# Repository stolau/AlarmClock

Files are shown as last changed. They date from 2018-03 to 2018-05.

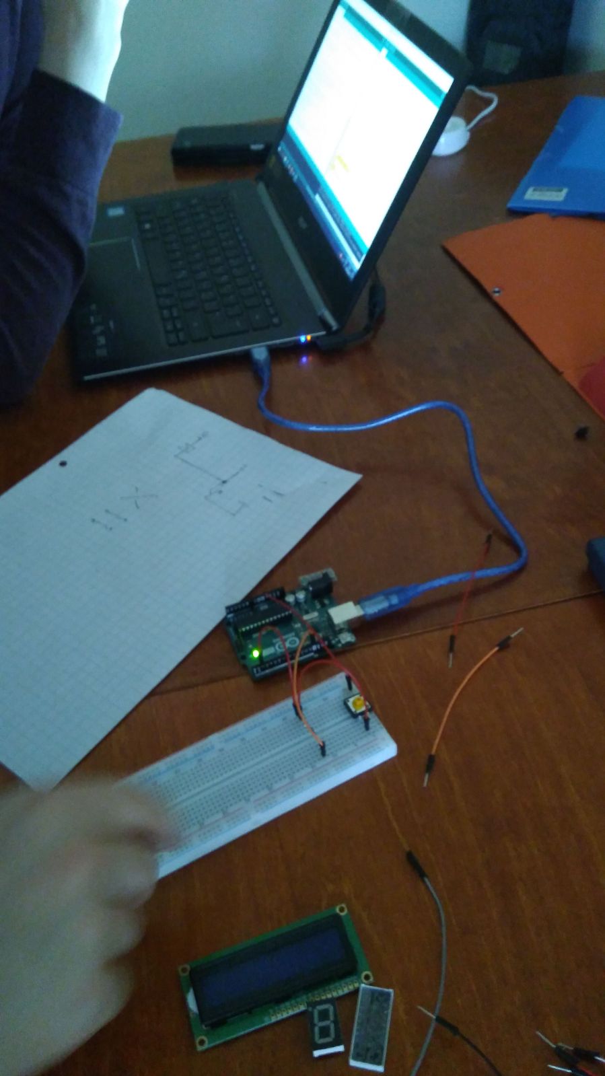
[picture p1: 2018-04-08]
Week 2 Report/Pictures/34270d8d-cade-4d01-affd-24c37ad5ccd0.jpg

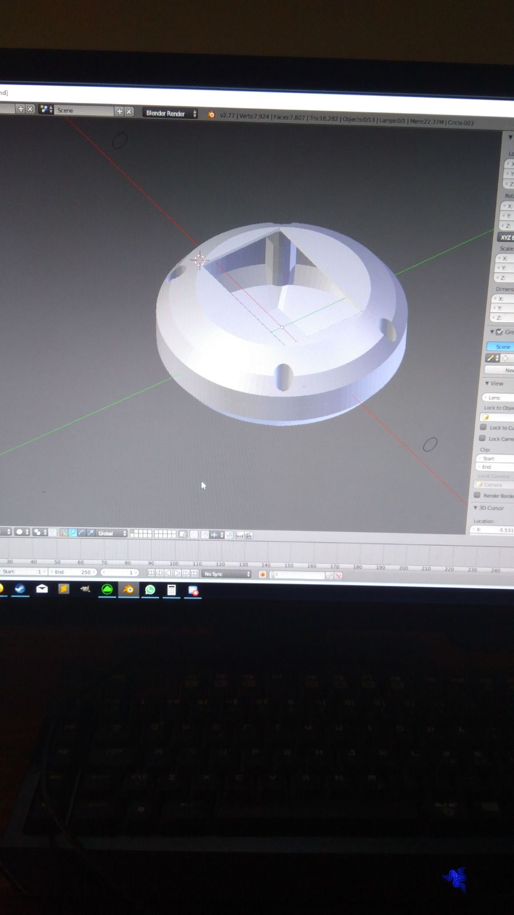
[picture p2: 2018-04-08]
Week 2 Report/Pictures/af725f57-4982-45e6-8ac4-7fc55cff98f3.jpg

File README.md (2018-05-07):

# Moving AlarmClock - Version 1.0

Simple clock which starts moving when alarm goes on. Based on arduino UNO.

Contains source code, files for 3D printable model and assigned weekly reports.

Model is printable with every 3D machine that supports .stl format. Also includes
original .blend file, which can be used to convert model for another formats.

All the libraries in Arduino file must be moved to arduino's library folder.

Known Bugs:
  Motors used in this project do not have enough power to move the clock.
  .stl files are scaled incorrectly, make sure you check the size before printing.

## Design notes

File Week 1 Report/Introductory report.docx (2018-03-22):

# Introductory report

We decided on the alarm clock which drives away when the alarm is activated. To shut it off we have thought about using the accelerometer, so when you shake it the alarm would go out.

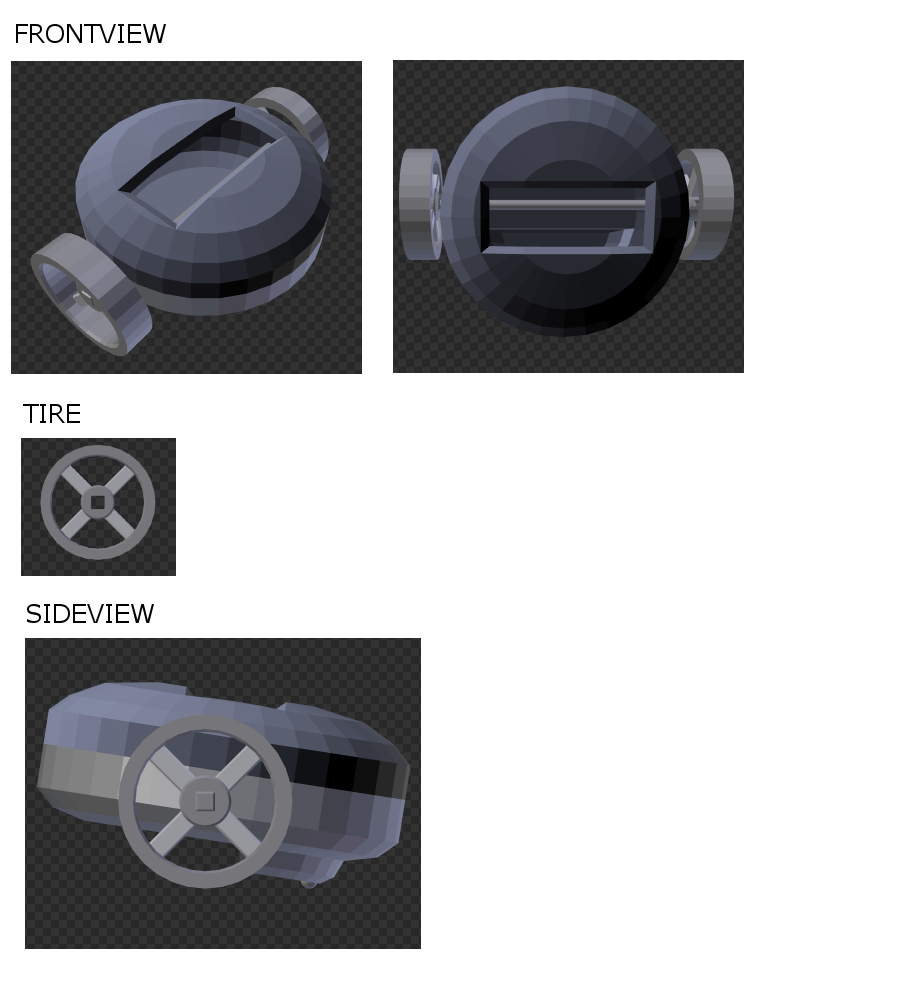
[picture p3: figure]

The decision to go with this design was easy, since this design is simple and should not be hard to build.

So far, Anssi has done some basic designs of the shell using Blender. We plan to have the wheels a bit more to the rear to keep it more balanced.

The lowest point of the shell is the holder for the battery, and since it will be touching the ground as the third point in addition to the wheels, we plan to put a ball that would roll to minimize friction.

Bill of Materials:

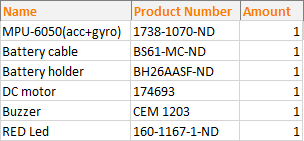
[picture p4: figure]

Anssi Uistola 2502616 Topias Syri 2504627 Juho Valkama 2503673

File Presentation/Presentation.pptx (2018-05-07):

## Alarm Clock

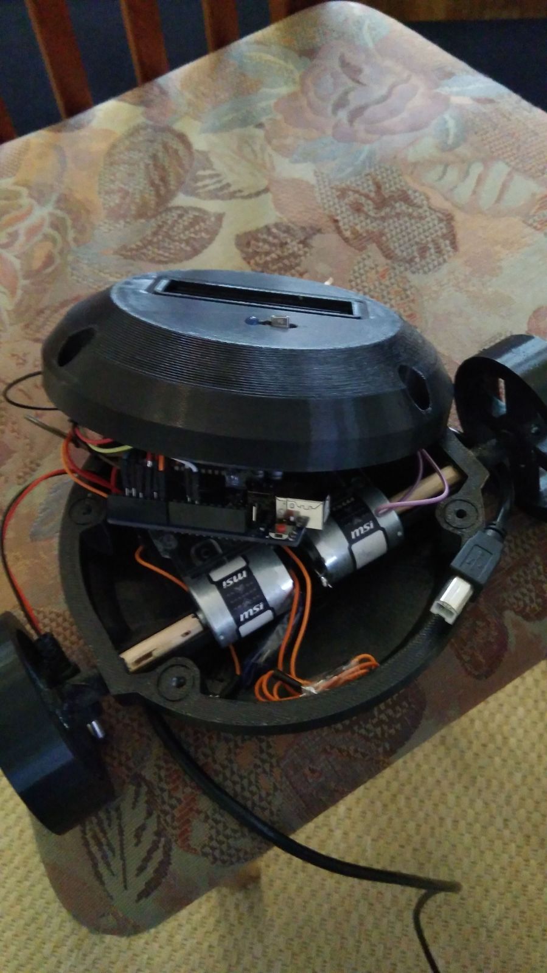
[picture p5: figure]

Anssi Uistola
Juho Valkama
Topias Syri

## Parts used

- Arduino UNO
- 16x2 LCD Screen
- MPU 6050
- 2x DC motors
- LED
- IR Receiver and remote

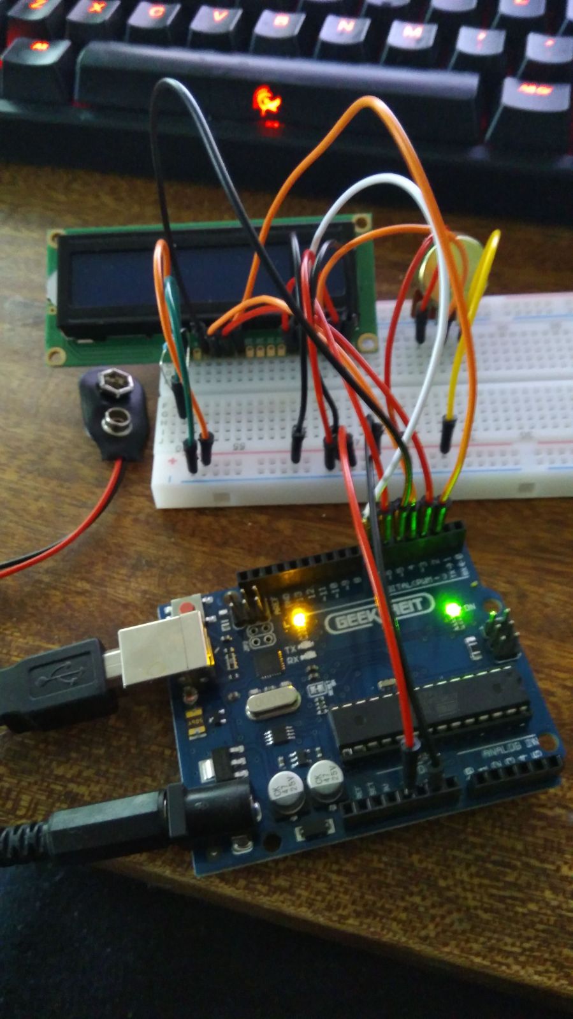
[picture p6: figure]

## Sketches of the final design

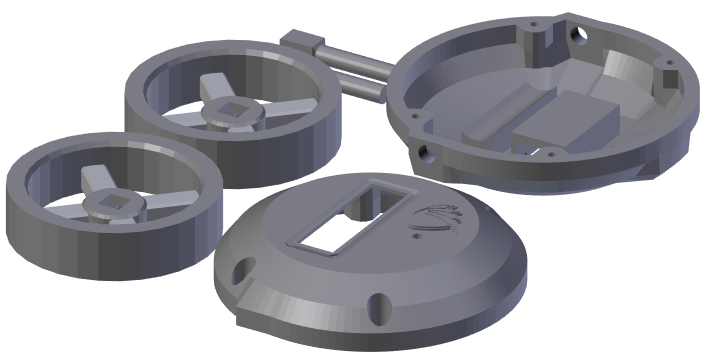
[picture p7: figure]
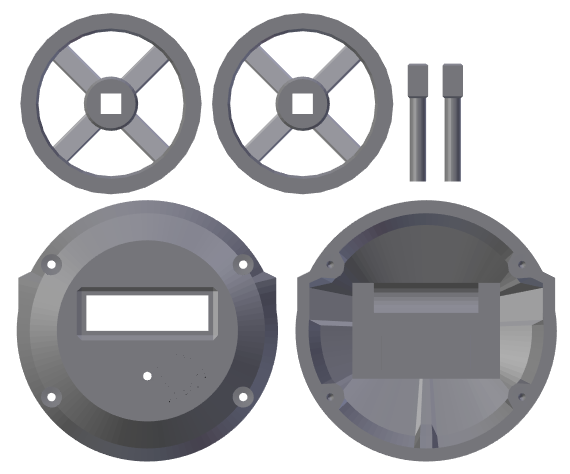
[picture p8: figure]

## Issues we had

- 3D-printing
- Wiring
- Assembly

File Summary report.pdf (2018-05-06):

Anssi Uistola 2502616
Topias Syri 2504627
Juho Valkama 2503673

# Alarm clock final report

## Aim of the project

We wanted to learn to work with Arduinos, and to learn how to model for 3D-printing. The default alarm clock project fit our needs for the project, so we decided to go with that design. Anssi had the vision for the shell of the clock, Topias knew how to do the connections needed and we knew that the code would not be a problem for us.

## Final product

Our final product consists of the 3D-printed shell, 16x2 LCD-screen, MPU6050, 2x DC motors, Arduino UNO, 1 LED, IR receiver and remote, and a buzzer.
Anssi has been responsible for the modeling of the shell, and the general leader of our project.
Topias has been responsible for the connections and the IR-receiver and remote.
Juho has been working with the code and other small tasks.
We had some problems with the 3D-printing, since the modeling was done with Blender, and importing the model from Blender to the software that the 3D-printer used had different scaling factors, the first printing produced parts that were too small. Because of this we had to do the printing again.
During the final assembly of the artifact we ran into some problems. The clock wasn't working, due to some issues with one of the wires.

Anssi Uistola 2502616
Topias Syri 2504627
Juho Valkama 2503673

Project pictures:

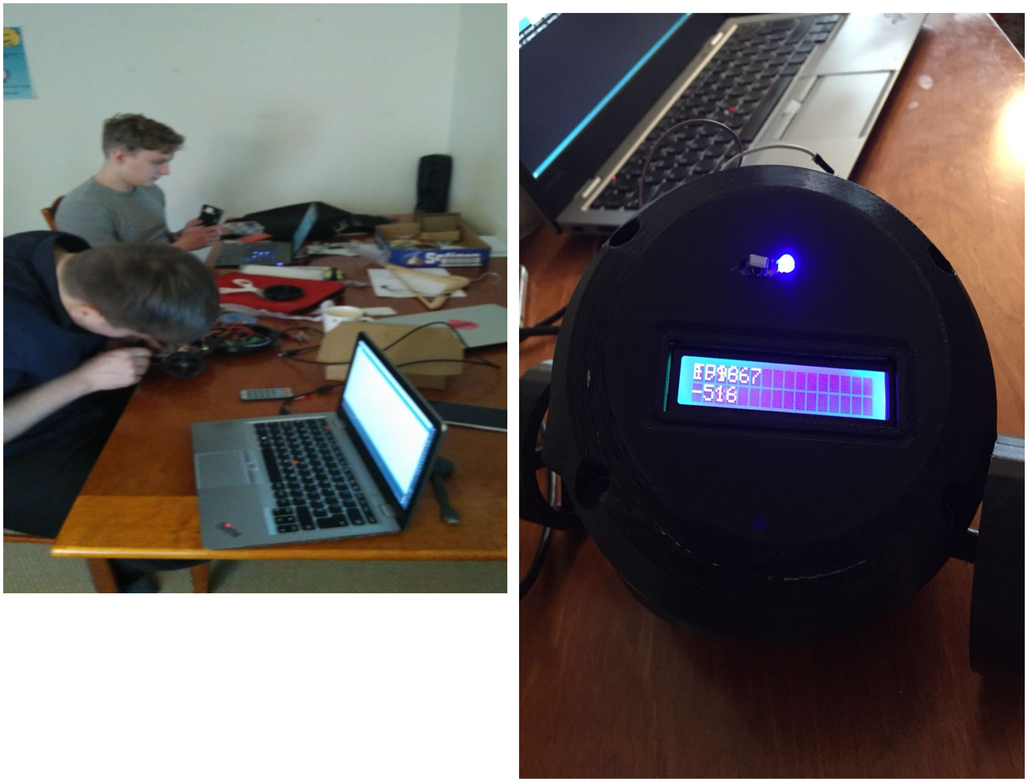
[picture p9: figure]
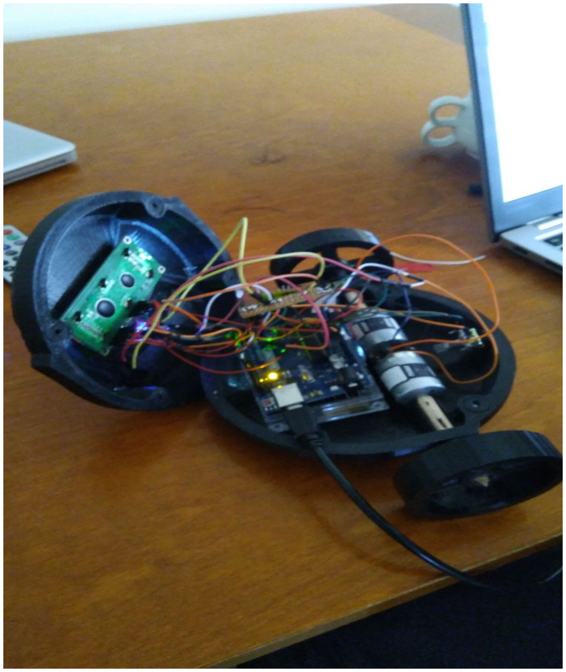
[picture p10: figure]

Link to source files and the presentation: https://github.com/stolau/AlarmClock

## Lessons learned

We haven't necessarily learnt anything new, but we have improved our existing skills, such as modeling and coding. We have all had our strengths, and this project has enabled us to teach each others.
For someone working on the same kind of project, we would recommend using more powerful motors, design the interior of the model carefully, so that all of the components fit perfectly. Plan the connections, so that the wiring on the final product is planned, and not just randomly inside the shell. As for the coding, learn to use the Arduino libraries, since many of the problems may already be resolved with them.

## Feedback

We would have liked if there was more information about the limitations of the 3D-printer.

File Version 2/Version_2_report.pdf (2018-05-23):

## AFTER THE FINAL PRESENTATION REPORT

(Version 2)

-Anssi Uistola, 2502616

-Juho Valkama, 2503673

-Topias Syri, 2504627

Idea

Once we assembled the artifact, we realized that some of the things were poorly designed and caused us

some troubles. Also we could not anticipate that motors were not strong enough to move the alarm clock.

So we decided to make so adjustments to the artifact for 2 reasons. Mostly because if someone would like

to build our artifact with our logs, models and code (for whatever reason), it would be great if they didn't have to do all the extra work we had to do. But also because our first 4 weeks reports were poorly made.

So to main problems we had with the final model.

Battery Hungry

Process

In the version 1, our code was refreshing LCD screen on every loop, which caused our 9V battery to

last only around 8hours. This was definatly not ideal if you are looking for alarm clock. We made screen to refresh, only if time actually changes. Which should increase duration of the battery alot.

Too Much Mass On The Shield

Version 1 model had lot more mass around the shield than it required. In version 2 we were able to

reduce mass by alot.

Wheels Not Moving The Clock

Process

Repositioned motors so we could fit in 4 ratchets inside. All of the 4 ratchets are connected with

each other, we should help with the movement.

Also added front wheel, which should reduce friction.

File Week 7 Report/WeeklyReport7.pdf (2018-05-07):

Weekly Report 7

-Anssi Uistola, 2502616

-Juho Valkama, 2503673

-Topias Syri, 2504627

Idea

The clock is ready, preparations for final presentation and some adjustments.

Process

There is not much to add to this weekly report since everything besides code and fitting parts inside the model was completly ready.

Our week was mostly spent programming and fixing few problems. Since all of us got back to Oulu this week, so we decided to heldout a bootcamp. Our code was splitted in to 3 parts and we were able to join them together quite easily.

Errors

We would have wanted to print axels aswell, but another machine was already on use (the one u cant reserve) So we had to make axels from wood. Luckily Anssi happened to have coat hanger which has almost perfectly shaped part. So Anssi pulled it out and made axels from it.

Once we assembled the final product and tried to test it out, we realized that motors could not move it once it was on the ground. We should have used force transmission tool, so it would move.

Also Anssi and Topias spent last 3hours trying to figure out why alarm is not going off. It turned out to bug in loop.

Reflections

Project is now completed. We had some problems in the road and many things could have been done smarter. But those things you learn from experience. Besides the moving tires, everything we planned was correctly delivered.

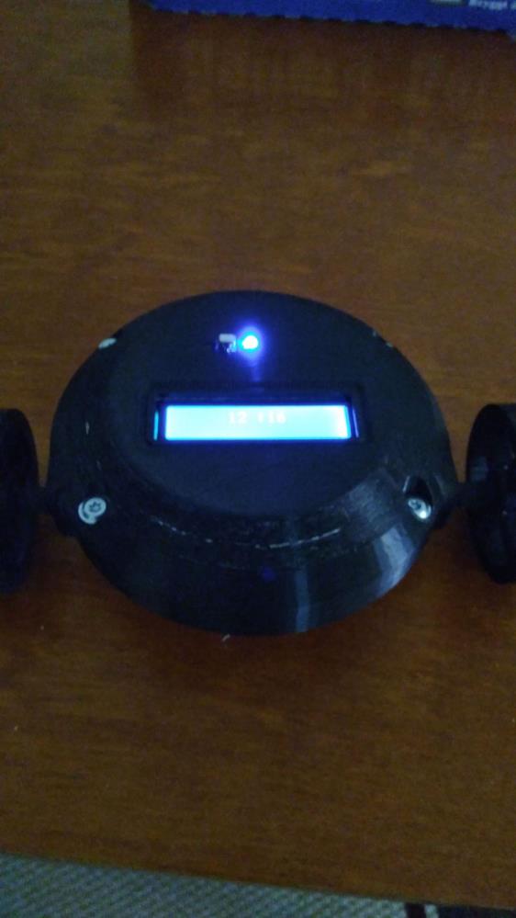
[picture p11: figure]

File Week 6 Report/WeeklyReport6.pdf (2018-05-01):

Weekly Report 6

-Anssi Uistola, 2502616

-Juho Valkama, 2503673

-Topias Syri, 2504627

Idea

Our idea is to finish the clock this week.

Code needs some tuning, we need to get our 3D parts and fit everything inside the clock.

Process

This week we had our 3D printing scheduled and it failed completly because while we were out, the machine ran out of material and we had no time to make it completly before our reservationtime ran out. Anyways we were lucky to get new reservation for the weekend, however because of the limitiations on how much we can print, we had to reserve new time to print axels and tires in smaller machine.

Also Topias finished soldering and all of our parts work nicely with arduino now.

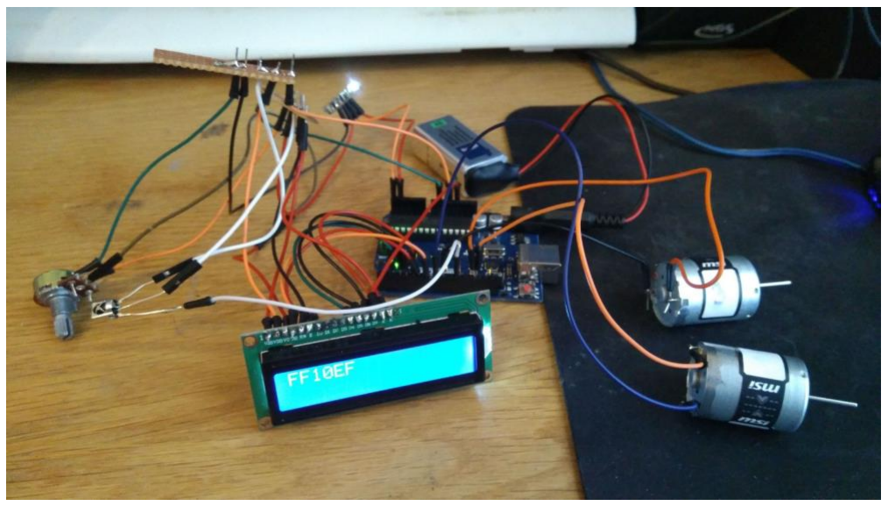
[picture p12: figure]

Juho coded the basic logic of the clock into the arduino. At the moment, it lacks the alarm function and the setting of the time.

Errors

Our first printing process failed, which was also good because we had error in our model which made it 2/3 of the size it should have been.

Topias got called to work 2 weeks earlier than he should have been. This will complicate things, because he is not in Oulu. Juho also started working this week, which makes time very valuable for us.

Also our schedule fell completly out of hand last weekend because of Topias had to start packing out of his apartment and Anssi and Juho were not able to get to computer. Luckily this only affected to our Weekly report, which was delayed couple of days because of that.

Reflections

Because of the problems last week with 3D printing. We got to use another printer for tires and axels. We hope that we don't encounter any issues with the another machine.

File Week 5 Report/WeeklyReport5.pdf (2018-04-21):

Weekly Report 5

-Anssi Uistola, 2502616

-Juho Valkama, 2503673

-Topias Syri, 2504627

Idea

Goal for the week was to get all the sensors to talk with Arduino

Process

We had our midterm presentation this week. Everything went well, but we realized that we would

want to make sure that axel would not bend because the pressure would only affect small area.

So we decided to even the pressure for larger area.

Also Topias connected our wireframe with arduino and explored more what kind of data we would get.

Juho made pseudocode based on state machine.

Errors

There was no huge errors, we found few mistakes. Those did not cause any problems for us.

More like anticipating few risks which would cause us more problems later.

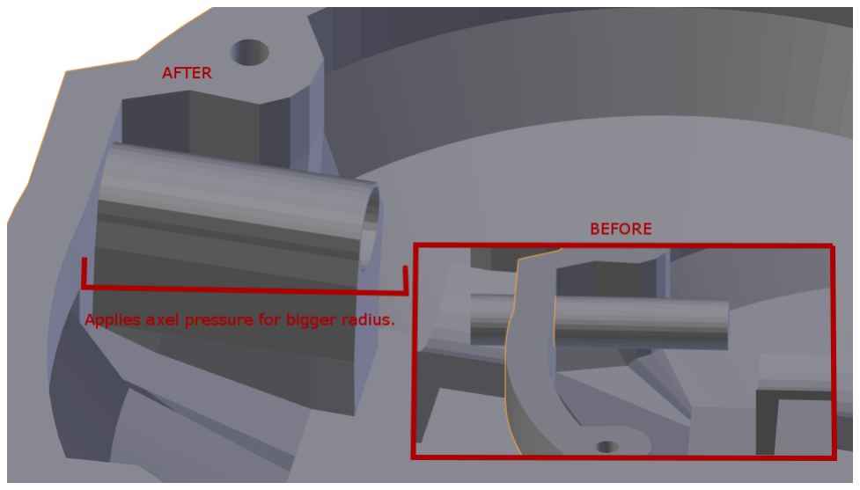
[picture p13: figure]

Reflections

Next week, we are planning to do the 3D printing. Which is probably most dangerous part of the

project for us, since nobody of us never done it before.

Also we will be switching full on coding since everything else should be ready.

If everything goes smoothly, we might have working project later this week.

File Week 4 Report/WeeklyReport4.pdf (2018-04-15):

Weekly Report 4

-Anssi Uistola, 2502616

-Juho Valkama, 2503673

-Topias Syri, 2504627

Idea

Our missing parts finally arrived and we have been studying how to connect them with arduino.

New parts included remote control, so we decided to use it in our final product.

Process

This week has been pretty quiet.

Anssi finished 3D model, there is few more questions about the model and if it fits in to the printer.

Topias and Juho have been focusing mostly on arduino.

Errors

We got printer reservation at 24.4. which is way later than we expected. So we must improvise

and make sure that all of our parts are ready, when model is out and can be set in place.

Reflections

Everyone is knows what they are supposed to do next and we might held out new meeting later next week.

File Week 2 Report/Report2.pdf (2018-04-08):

Weekly report 3

-Anssi Uistola, 2502616

-Juho Valkama, 2503673

-Topias Syri, 2504627

Idea

We have started the practical work on the prototype.

We are not quite sure yet if we will use buttons or a remote to control the device

Process

We held a 4-hour long meeting at Anssi's place, where we did the majority of the work for this week.

We have received the parts, and started testing different things with the Arduinos.

The design model was completely overhauled to include holes for screws, and other small improvements, such as the location for the wheels.

Errors

The first iteration of the model was not good, so it had to be completely redesigned

Reflections

We have quite a good feeling about this project, and haven't yet had any major issues.

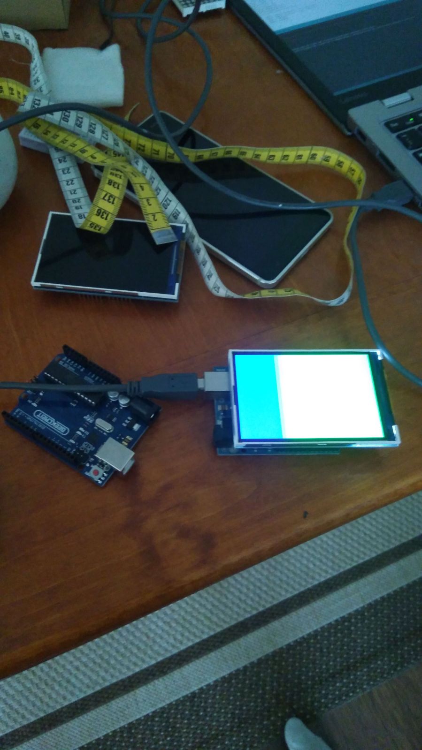
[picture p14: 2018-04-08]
Week 2 Report/Pictures/09ff2875-0148-424b-82e7-91542ec2c2b0.jpg

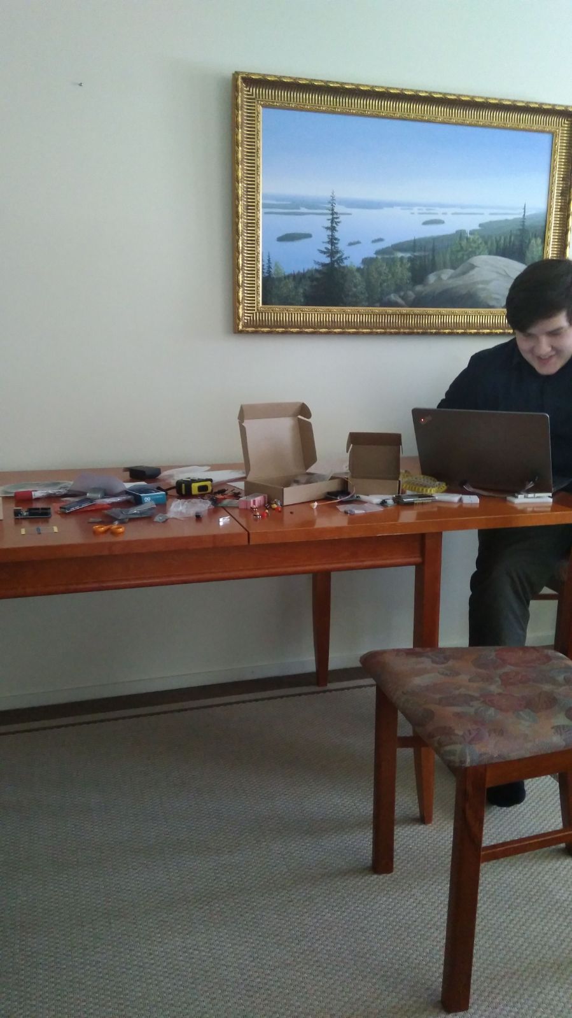
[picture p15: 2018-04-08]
Week 2 Report/Pictures/3be39771-2107-4257-a7a4-567ca8e624e5.jpg

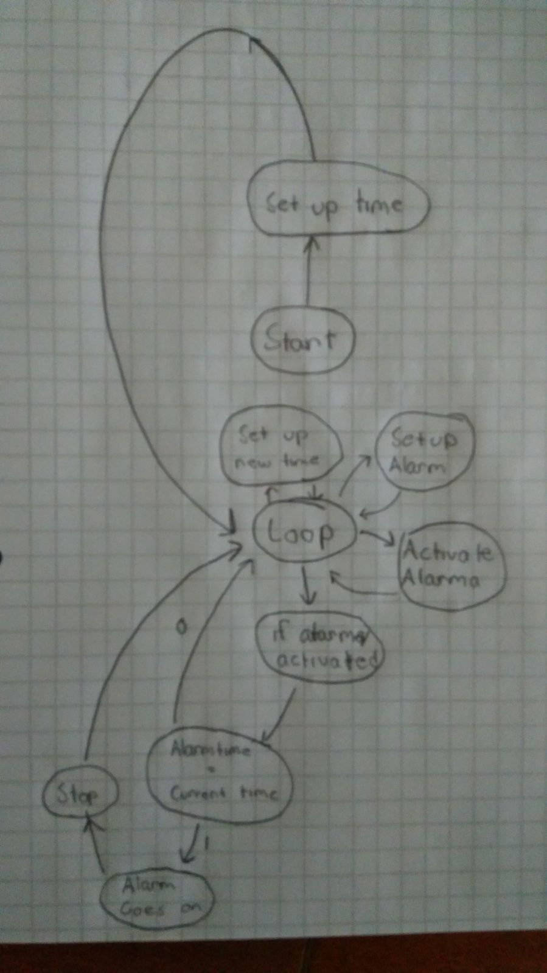
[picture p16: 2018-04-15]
Week 4 Report/Pictures/stateDiagram.jpeg

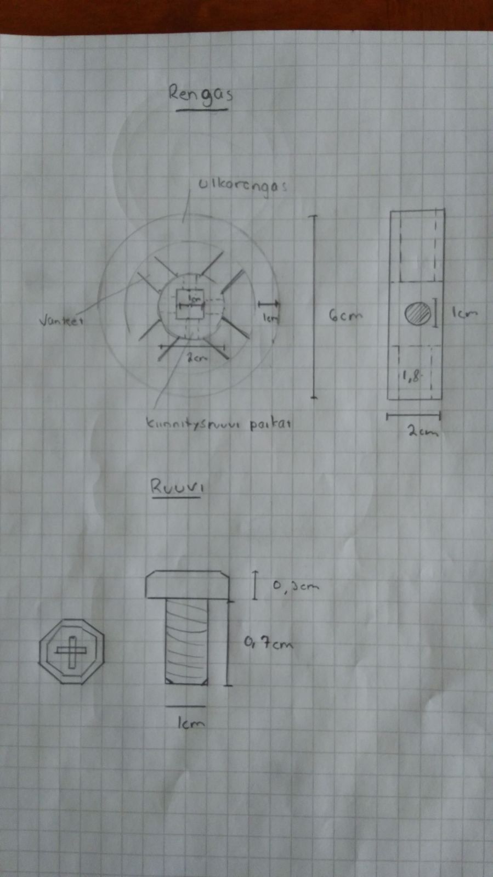
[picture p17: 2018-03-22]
Week 1 Report/Initial_sketches_of_model/AlarmClockSketch_02.jpeg

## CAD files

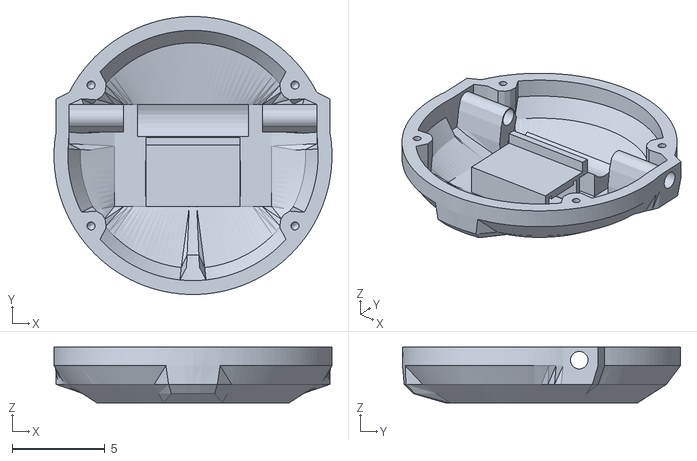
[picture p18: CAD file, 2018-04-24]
Model/alarmBotFixed.stl
15.0 x 15.0 x 3.00

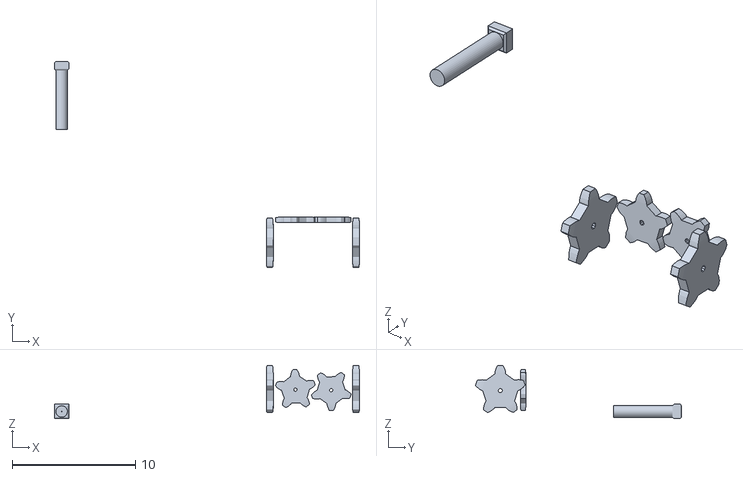
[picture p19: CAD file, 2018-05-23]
Version 2/Model_v2/AlarmClockBackWheelAxel.stl
24.8 x 16.7 x 4.32

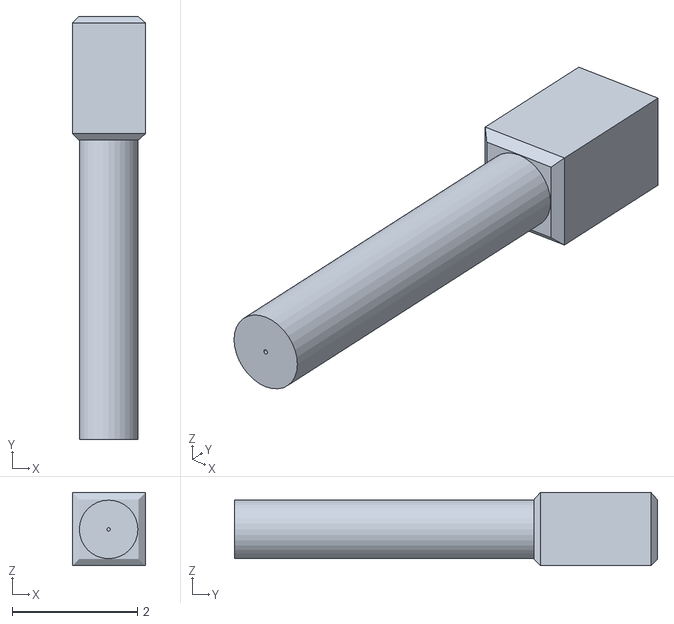
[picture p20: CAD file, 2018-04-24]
Model/alarmAxelFixed.stl
1.17 x 6.76 x 1.17

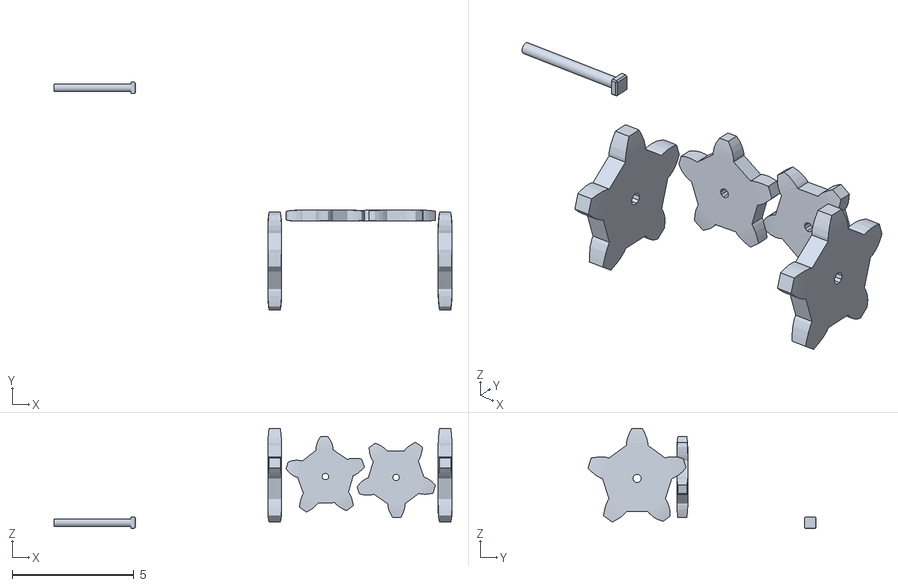
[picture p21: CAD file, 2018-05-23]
Version 2/Model_v2/AlarmClockFrontWheelAxel.stl
16.3 x 9.37 x 4.11

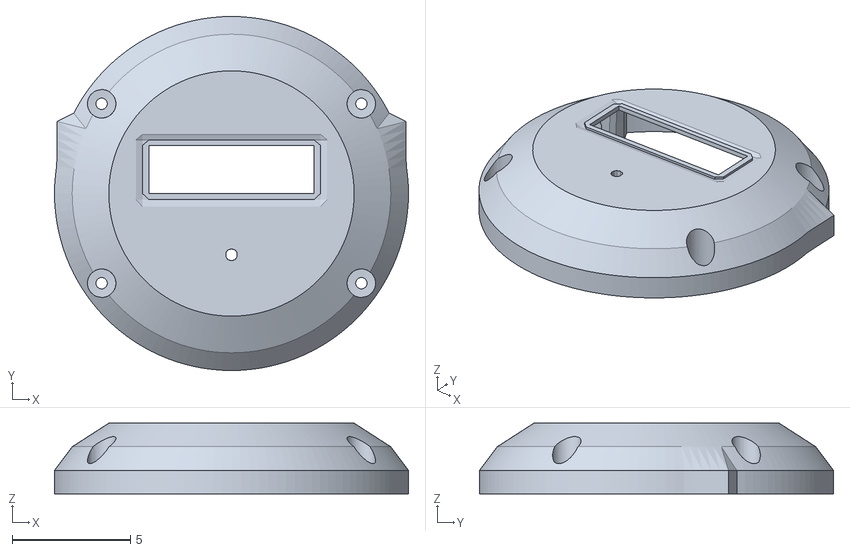
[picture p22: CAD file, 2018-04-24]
Model/alarmTop100.stl
15.0 x 15.0 x 3.00

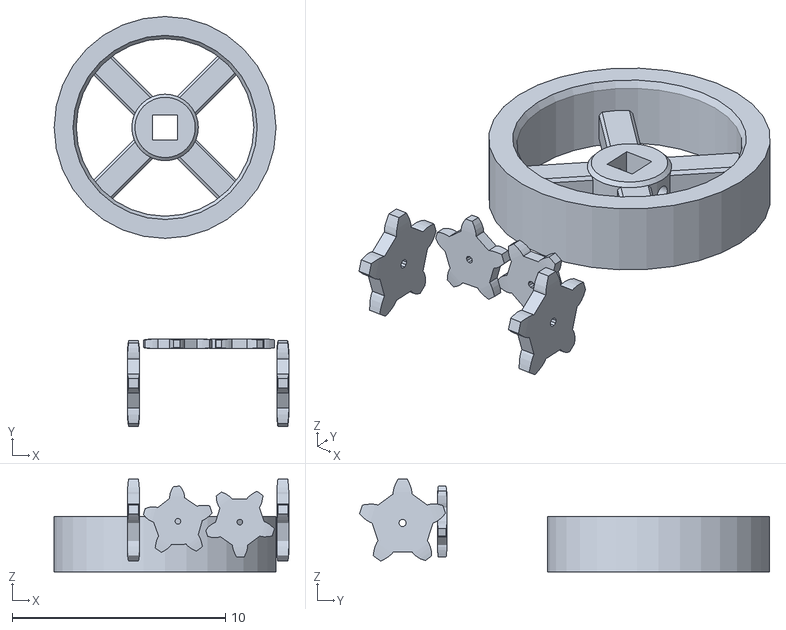
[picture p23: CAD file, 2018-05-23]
Version 2/Model_v2/AlarmClockBackWheel.stl
11.0 x 19.2 x 4.34

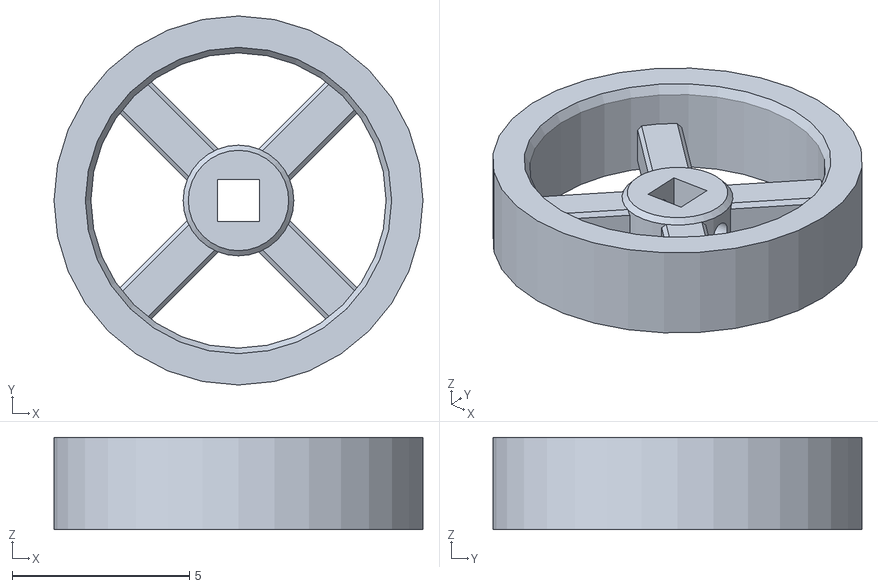
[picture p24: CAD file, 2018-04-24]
Model/tirelNew100.stl
10.4 x 10.4 x 2.60

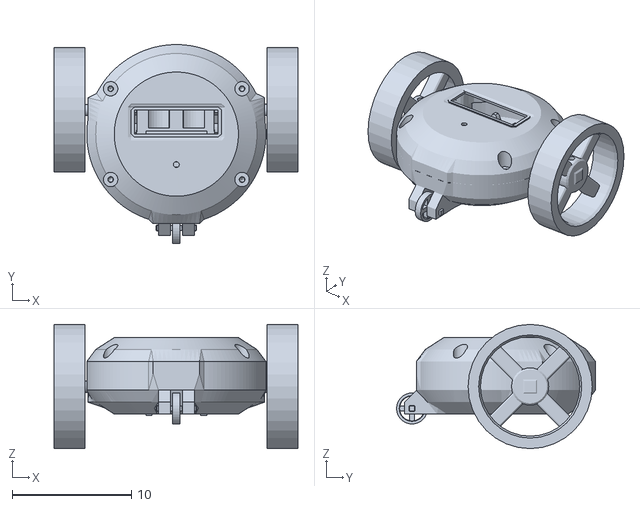
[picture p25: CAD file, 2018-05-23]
Version 2/Model_v2/AlarmClockVersion2.stl
20.4 x 16.7 x 10.4

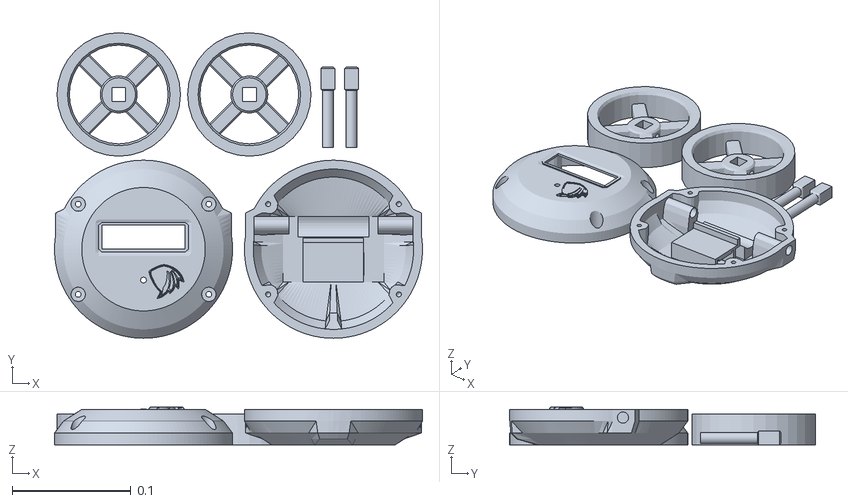
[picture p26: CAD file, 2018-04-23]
Model/alarmClockModelNew.stl
0.31 x 0.257 x 0.0318

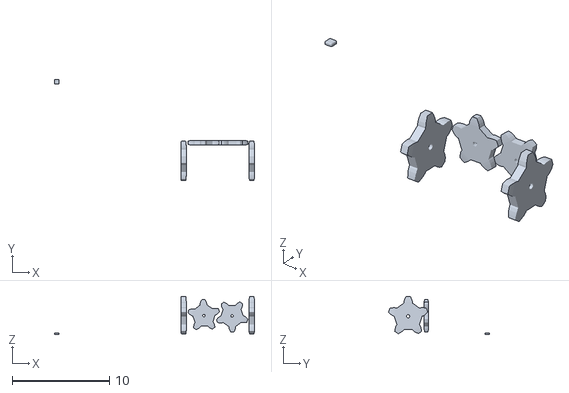
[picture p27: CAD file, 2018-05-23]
Version 2/Model_v2/AlarmClockFrontWheelAxelsHolder.stl
20.5 x 10.4 x 3.94

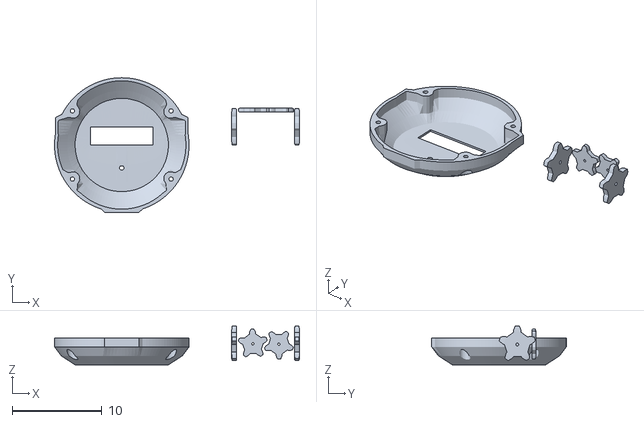
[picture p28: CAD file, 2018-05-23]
Version 2/Model_v2/AlarmClockTop.stl
27.3 x 15.0 x 4.32

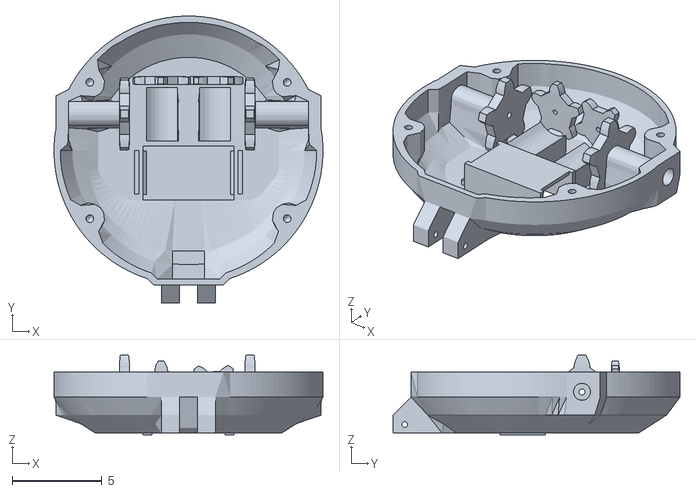
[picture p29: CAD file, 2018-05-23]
Version 2/Model_v2/AlarmClockBottomstl.stl
15.0 x 16.0 x 4.44

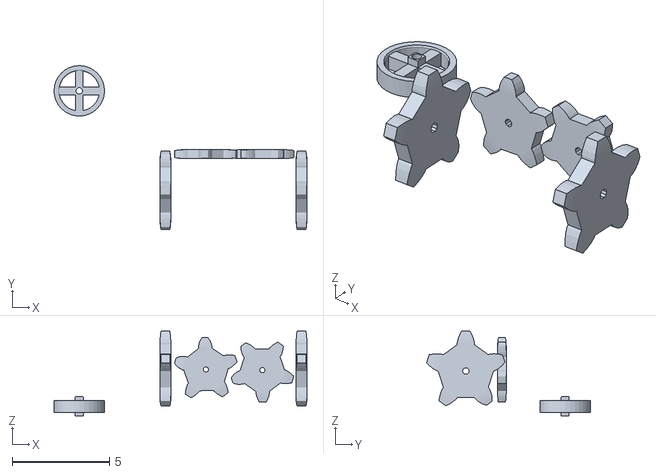
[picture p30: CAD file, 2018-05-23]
Version 2/Model_v2/AlarmClockFrontWheel.stl
13.0 x 8.43 x 4.36

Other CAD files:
Model/alarmClockModelNew.blend
Model/alarmFixed.blend

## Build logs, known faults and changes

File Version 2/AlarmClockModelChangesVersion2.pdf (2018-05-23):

## Alarm Clock v2: MODEL UPDATES

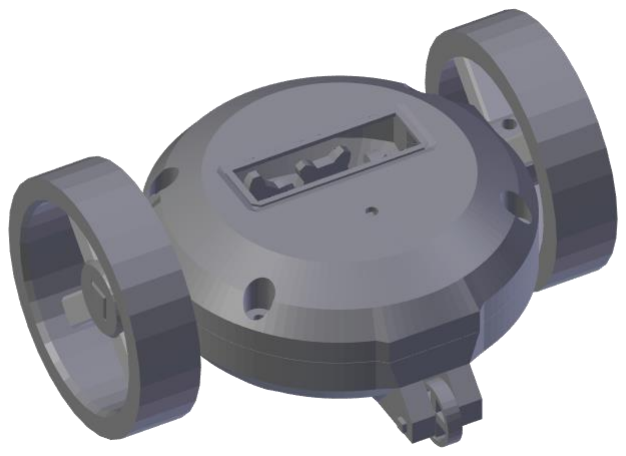
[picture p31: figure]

Summary of changes:

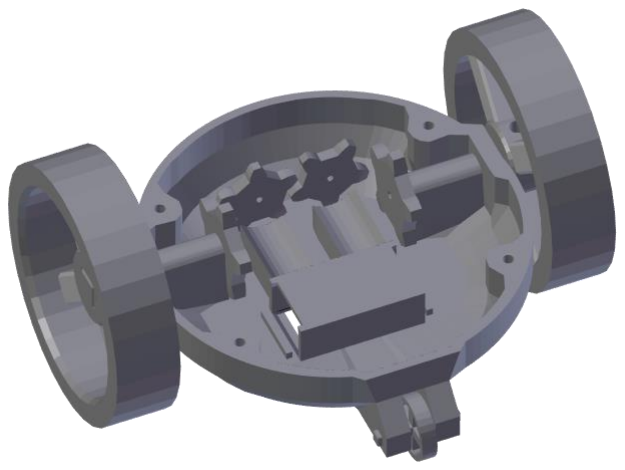
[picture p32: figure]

- Repositioned motor holders so, to add 4 ratchets to help clock move better
- Made rathets.
- Small adjustments to battery container, so battery can be placed and removed easier.
- Added front wheel, which would reduce friction.
- Removed extra mass from sides. Shield is now around 2 times thiner than it was on first version.
- Strengthened screw places on top shield, so they would not break that easily
- Strengthened axel holders, so they would not break that easily.

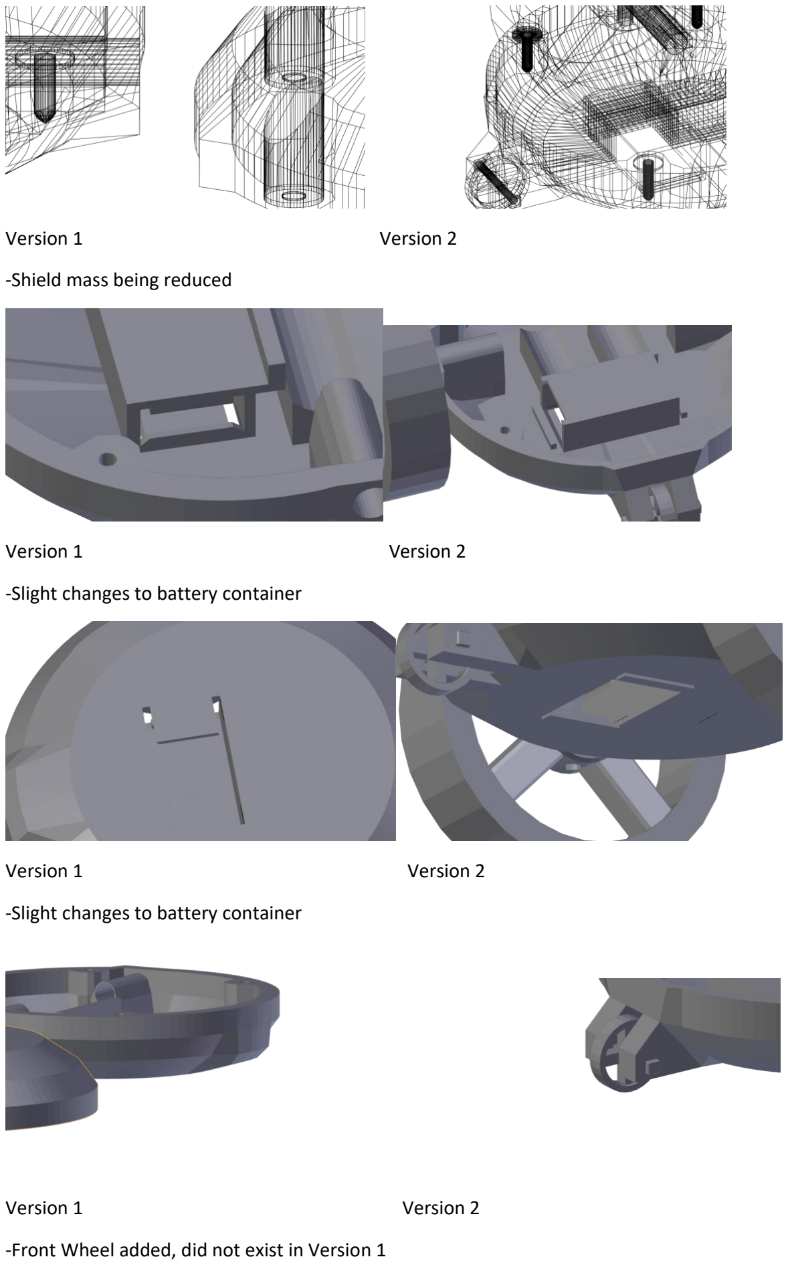
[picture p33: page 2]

Version 1 | Version 2

-Shield mass being reduced

Version 1 | Version 2

-Slight changes to battery container

Version 1 | Version 2

-Slight changes to battery container

Version 1 | Version 2

-Front Wheel added, did not exist in Version 1

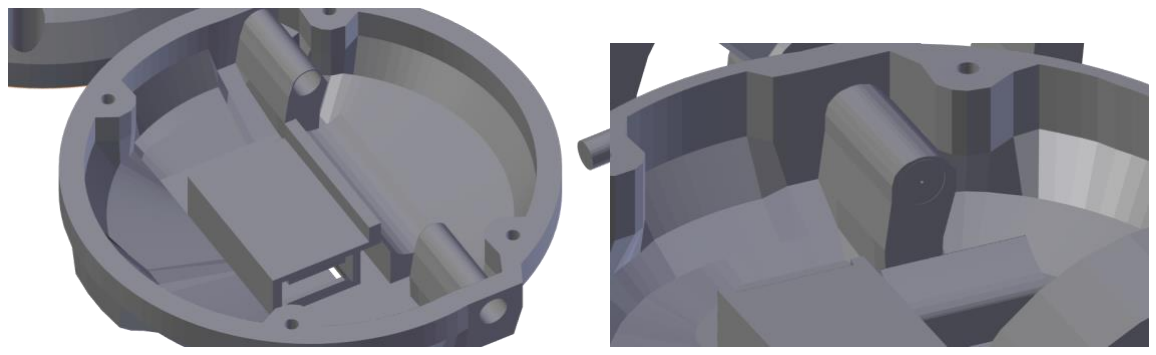
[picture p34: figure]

Version 1 | Version 2

-Strengthened axel holders and repositioned motor holders.

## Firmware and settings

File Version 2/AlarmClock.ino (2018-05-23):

// Include Libraries
#include "Arduino.h"
#include "LiquidCrystal.h"
#include "MPU6050.h"
#include "Wire.h"
#include "I2Cdev.h"
#include "IR.h"
#include "IRremote.h"
#include "IRremoteInt.h"
#include "TimeAlarms.h"
#include "Time.h"


// Pin Definitions
#define LCD_PIN_RS  7
#define LCD_PIN_E 6
#define LCD_PIN_DB4 2
#define LCD_PIN_DB5 3
#define LCD_PIN_DB6 4
#define LCD_PIN_DB7 5

#define SPEAKER 10

#define MOTOR_1 8
#define LED_1 9

int timeSetup();

// Global variables and defines
int16_t mpu6050Ax, mpu6050Ay, mpu6050Az;
int16_t mpu6050Gx, mpu6050Gy, mpu6050Gz;

// Global variables for loop
bool alarmFlag = false;
int timeHours = 12;
int timeMins = 12;
int alarmHours = -1;
int alarmMins = -1;
int alarmTime = 0;
int number;
int maxNum;

// object initialization
LiquidCrystal lcd(LCD_PIN_RS,LCD_PIN_E,LCD_PIN_DB4,LCD_PIN_DB5,LCD_PIN_DB6,LCD_PIN_DB7);
MPU6050 mpu6050;


// define vars for testing menu
int a = 1;
int RECV_PIN = 11;

IRrecv irrecv(RECV_PIN);

decode_results results;
int giveNumber(int maxNum, int IRresult);
// Setup the essentials for your circuit to work. It runs first every time your circuit is powered with electricity.
void setup() 
{
    pinMode(MOTOR_1, OUTPUT);
    pinMode(LED_1, OUTPUT);
    pinMode(SPEAKER, OUTPUT);
    Serial.begin(9600);
    Wire.begin();
    mpu6050.initialize();
    irrecv.enableIRIn();
    setTime(timeHours, timeMins, 53, 0, 0, 0);
    lcd.begin(16, 2);  
}

void AlarmOn()
{
  int wait = 300;
  int shake_count = 0;
  int shake_tr = 10;
  int treshold = 1200;
  int fl = 1;
  //digitalWrite(MOTOR_1, HIGH);
  while(shake_tr > shake_count)
  {
    if(irrecv.decode(&results))
    {
      if(results.value == 0xA857)
      {
        break;
      }
    }
    mpu6050.getMotion6(&mpu6050Ax, &mpu6050Ay, &mpu6050Az, &mpu6050Gx, &mpu6050Gy, &mpu6050Gz);
    int gx1 = mpu6050Gx;
    int gy1 = mpu6050Gy;
    int gz1 = mpu6050Gz;
    analogWrite(SPEAKER, 12);
    digitalWrite(LED_1, HIGH);
    delay(wait);
    analogWrite(SPEAKER, 0);
    delay(wait);
    irrecv.resume();
    mpu6050.getMotion6(&mpu6050Ax, &mpu6050Ay, &mpu6050Az, &mpu6050Gx, &mpu6050Gy, &mpu6050Gz);
    int gx2 = mpu6050Gx;
    int gy2 = mpu6050Gy;
    int gz2 = mpu6050Gz;
    if((abs(gx2 - gx1) >= treshold) or (abs(gy2 - gy1) >= treshold) or (abs(gz2-gz1) >= treshold))
	{
      shake_count += 1;
    }
    if(shake_count >= shake_tr)
      {
       analogWrite(SPEAKER, 0);
      break;
      }    
   }
  //digitalWrite(MOTOR_1, LOW);
 }


// Main Loop, waits for command and keeps the clock ticking
void loop() 
{
  // Screen is only refreshed if seconds are over 58-02
  if(second(now()) > 59 or second(now()) < 1)
  {
    lcd.clear();
    lcd.setCursor(5,0);
    lcd.print(hour(now()));
    lcd.setCursor(8,0);
    lcd.print(":");
    lcd.setCursor(9,0);
    lcd.print(minute(now()));
    if(alarmFlag == true)
    {
      lcd.setCursor(0, 1);
      lcd.print("** ");
      lcd.setCursor(5, 1);
      lcd.print(alarmHours);
      lcd.setCursor(8, 1);
      lcd.print(":");
      lcd.setCursor(9, 1);
      lcd.print(alarmMins);
      if(hour(now())==alarmHours && minute(now())==alarmMins)
      {
        AlarmOn();
        alarmFlag = false;
      }
    }
    }
  if (irrecv.decode(&results))
  {
    // To setup new time for clock
    // Mark CH
    if(results.value == 0xFF629D)
    {
    
    // uses setupTime function to determine time
      lcd.clear();
      lcd.setCursor(5,0);
      lcd.print(hour(now()));
      lcd.setCursor(8,0);
      lcd.print(":");
      lcd.setCursor(9,0);
      lcd.print(minute(now()));
      lcd.setCursor(0,1);
      lcd.print("Setup Time: ");
	    timeHours = hourSetup();
      timeMins = minsSetup();
      setTime(timeHours, timeMins, 53, 0, 0, 0);
    }
      // Activates Alarm (Turns alarm and LED)
      // Mark EQ
    if(results.value == 0xFF906F)
    {
      if(alarmFlag == true)
      {
      // Deactivates alarm time here
      // Turns alarmFlag off
      // 
        digitalWrite(LED_1, LOW);
        alarmFlag = false;
      }
     else
      {
          // Checks if there is already alarmTime, if not asks for user input
        if(alarmHours == -1 && alarmMins == -1)
        {
          lcd.clear();
          lcd.setCursor(5,0);
          lcd.print(hour(now()));
          lcd.setCursor(8,0);
          lcd.print(":");
          lcd.setCursor(9,0);
          lcd.print(minute(now()));
          lcd.setCursor(0,1);
          lcd.print("Set Alarm: ");
          alarmHours = hourSetup();
	        alarmMins = minsSetup();
        }
        digitalWrite(LED_1, HIGH);
        alarmFlag = true;
        lcd.setCursor(0, 1);
        lcd.print("** ");
        lcd.setCursor(5, 1);
        lcd.print(alarmHours);
        lcd.setCursor(8, 1);
        lcd.print(":");
        lcd.setCursor(9, 1);
        lcd.print(alarmMins);
      // Turns LED on
      }
    }
    // Setups new ALARMtime
    // Mark CH+
    if(results.value == 0xFFE21D)
    {
      lcd.clear();
      lcd.setCursor(5,0);
      lcd.print(hour(now()));
      lcd.setCursor(8,0);
      lcd.print(":");
      lcd.setCursor(9,0);
      lcd.print(minute(now()));
      lcd.setCursor(0,1);
      lcd.print("Set Alarm: ");
	  alarmHours = hourSetup();
	  alarmMins = minsSetup();
    }
    irrecv.resume();
    }
    delay(100);

}
int hourSetup()
{
	int hourNum = 2;
	int maxNum = 0;
	int setHour = 0;
	// Loops here until 2 digits to indicate hours are marked
    while(hourNum > 0)
    {
      int number = -1;
      if(irrecv.decode(&results))
      {
        // Checks if its first digit
        if(hourNum == 2)
        {
          maxNum = 2;
          number = giveNumber(maxNum, results.value);
          irrecv.resume();
          if(number >= 0)
          {
            number = number * 10;
            setHour = setHour + number;
            hourNum = hourNum - 1;
            lcd.setCursor(11, 1);
            lcd.print(setHour);
          }
        }
        // If not its second digit
        else
        {
          // lcd.clear();
          // lcd.print("Dadaa22");
          if(setHour < 20)
          {
            maxNum = 9;
            number = giveNumber(maxNum, results.value);
            irrecv.resume();
            if(number >= 0)
            {
              setHour = setHour + number;
              hourNum = hourNum - 1;
              lcd.setCursor(11, 1);
              lcd.print(setHour);
            }
           }
           else
           {
             maxNum = 3;
             number = giveNumber(maxNum, results.value);
             irrecv.resume();
             if(number >= 0)
             {
               setHour = setHour + number;
               hourNum = hourNum - 1;
               lcd.setCursor(11, 1);
               lcd.print(setHour);
             }
            } 
          }
		}
    }
	return setHour;
}
int minsSetup()
{
	int minsNum = 2;
	int maxNum = 0;
	int setMin = 0;
	
    while(minsNum > 0)
    {
      // lcd.clear();
      // lcd.print("Dadaa");
      if(irrecv.decode(&results))
      {
        // Checks if its first digit
        if(minsNum == 2)
        {
          maxNum = 5;
          number = giveNumber(maxNum, results.value);
          irrecv.resume();
          if(number > 0)
          {
            number = number * 10;
            setMin = setMin + number;
            minsNum = minsNum - 1;
            lcd.setCursor(13, 1);
            lcd.print(":");
            lcd.setCursor(14, 1);
            lcd.print(setMin);
          }
        }
        // If not its second digit
        else
        {
            maxNum = 9;
            number = giveNumber(maxNum, results.value);
            irrecv.resume();
            if(number >= 0)
            {
              setMin = setMin + number;
              minsNum = minsNum - 1;
              lcd.setCursor(13, 1);
              lcd.print(":");
              lcd.setCursor(14, 1);
              lcd.print(setMin);
            }
         }
      }
    }

  return setMin;
}

// Function transferms hexdigit from receiver to number
// Also checks out if there is limitations to 00:00-23:59 clocksystem
int giveNumber(int maxNum, int IRresult)
{
  //lcd.print(IRresult, HEX);
  // Mark 0
  if(IRresult == 0x6897)
  {
    return 0;
  }
  // Mark 1
  if(IRresult == 0x30CF)
  {
    return 1;
  }
  if(IRresult == 0x18E7)
  {
    return 2;
  }
  //  Mark 3
  if(IRresult == 0x7A85)
  {
    if(maxNum >= 3)
    {
      return 3;
    }
    else
    {
      // Aborted mission
      lcd.print("1");
      return -1;
    }
  }
  //  Mark 4
  if(IRresult == 0x10EF)
  {
    if(maxNum >= 4)
    {
      return 4;
    }
    else
    {
      // Aborted mission
      lcd.print("2");
      return -1;
    }
  }
  //  Mark 5
  if(IRresult == 0x38C7)
  {
    if(maxNum >= 5)
    {
      return 5;
    }
    else
    {
      // Aborted mission
      return -1;
    }
  }
  //  Mark 6
  if(IRresult == 0x5AA5)
  {
    if(maxNum >= 6)
    {
      return 6;
    }
    else
    {
      // Aborted mission
      return -1;
    }
  }
  //  Mark 7
  if(IRresult == 0x42BD)
  {
    if(maxNum >= 7)
    {
      return 7;
    }
    else
    {
      // Aborted mission
      return -1;
    }
  }
  //  Mark 8
  if(IRresult == 0x4AB5)
  {
    if(maxNum >= 8)
    {
      return 8;
    }
    else
    {
      // Aborted mission
      return -1;
    }
  }
  //  Mark 9
  if(IRresult == 0x52AD)
  {
    if(maxNum >= 9)
    {
      return 9;
    }
    else
    {
      // Aborted mission
      return -1;
    }
  }
  else
  {
    return -1;
  }
  
  
}

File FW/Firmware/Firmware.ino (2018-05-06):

// Include Libraries
#include "Arduino.h"
#include "MPU6050.h"
#include "Wire.h"
#include "I2Cdev.h"
#include "IR.h"
#include "IRremote.h"
#include "IRremoteInt.h"


// Pin Definitions
#define IR_PIN_OUT	2



// Global variables and defines
int16_t mpu6050Ax, mpu6050Ay, mpu6050Az;
int16_t mpu6050Gx, mpu6050Gy, mpu6050Gz;
// object initialization
MPU6050 mpu6050;
IR ir(IR_PIN_OUT);



// define vars for testing menu
const int timeout = 10000;       //define timeout of 10 sec
char menuOption = 0;
long time0;

// Setup the essentials for your circuit to work. It runs first every time your circuit is powered with electricity.
void setup() 
{
    // Setup Serial which is useful for debugging
    // Use the Serial Monitor to view printed messages
    Serial.begin(9600);
    while (!Serial) ; // wait for serial port to connect. Needed for native USB
    Serial.println("start");
    
    Wire.begin();
    mpu6050.initialize();
    // initialize IR device
    ir.init();
    menuOption = menu();
    
}

// Main logic of your circuit. It defines the interaction between the components you selected. After setup, it runs over and over again, in an eternal loop.
void loop() 
{
    
    
    if(menuOption == '1') {
    // SparkFun MPU-6050 - Accelerometer and Gyro - Test Code
    mpu6050.getMotion6(&mpu6050Ax, &mpu6050Ay, &mpu6050Az, &mpu6050Gx, &mpu6050Gy, &mpu6050Gz);   //read accelerometer and gyroscope raw data in three axes
    double mpu6050Temp = ((double)mpu6050.getTemperature() + 12412.0) / 340.0;
    Serial.print("a/g-\t");
    Serial.print(mpu6050Ax); Serial.print("\t");
    Serial.print(mpu6050Ay); Serial.print("\t");
    Serial.print(mpu6050Az); Serial.print("\t");
    Serial.print(mpu6050Gx); Serial.print("\t");
    Serial.print(mpu6050Gy); Serial.print("\t");
    Serial.print(mpu6050Gz); Serial.print("\t");
    Serial.print(F("Temp- "));   
    Serial.println(mpu6050Temp);
    delay(100);

    }
    else if(menuOption == '2') {
    // IR Receiver Diode - TSOP38238 - Test Code
    //Receive IR code into irCode
    long irCode =  ir.detect();
    // if a code was received print it to serial monitor, note that the code is of type long but printed in HEX
    // Consider changing the if statment to something like: if(irCode == "YOUR IR CODE")
    if(irCode)
    {
        Serial.print("0x");
        Serial.println(irCode, HEX);
    }
    }
    
    
    
    if (millis() - time0 > timeout)
    {
        menuOption = menu();
    }
    
}



// Menu function for selecting the components to be tested
// Follow serial monitor for instrcutions
char menu()
{

    Serial.println(F("\nWhich component would you like to test?"));
    Serial.println(F("(1) SparkFun MPU-6050 - Accelerometer and Gyro"));
    Serial.println(F("(2) IR Receiver Diode - TSOP38238"));
    Serial.println(F("(menu) send anything else or press on board reset button\n"));
    while (!Serial.available());

    // Read data from serial monitor if received
    while (Serial.available()) 
    {
        char c = Serial.read();
        if (isAlphaNumeric(c)) 
        {
            if(c == '1') 
    			Serial.println(F("Now Testing SparkFun MPU-6050 - Accelerometer and Gyro"));
    		else if(c == '2') 
    			Serial.println(F("Now Testing IR Receiver Diode - TSOP38238"));
            else
            {
                Serial.println(F("illegal input!"));
                return 0;
            }
            time0 = millis();
            return c;
            }
        }
    }

/*******************************************************

*    Circuito.io is an automatic generator of schematics and code for off
*    the shelf hardware combinations.

*    Copyright (C) 2016 Roboplan Technologies Ltd.

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
CHANTABILITY, TITLE, FITNESS 
*    FOR A PARTICULAR PURPOSE, NON-INFRINGEMENT, AND THOSE ARISING BY 
*    STATUTE OR FROM A COURSE OF DEALING OR USAGE OF TRADE. 
*    YOUR RELIANCE ON, OR USE OF THIS PROGRAM IS AT YOUR SOLE RISK.
*    ROBOPLAN DOES NOT GUARANTEE THAT THE PROGRAM WILL BE FREE OF, OR NOT 
*    SUSCEPTIBLE TO, BUGS, SECURITY BREACHES, OR VIRUSES. ROBOPLAN DOES 
*    NOT WARRANT THAT YOUR USE OF THE PROGRAM, INCLUDING PURSUANT TO 
*    SCHEMATICS, INSTRUCTIONS OR RECOMMENDATIONS OF ROBOPLAN, WILL BE SAFE 
*    FOR PERSONAL USE OR FOR PRODUCTION OR COMMERCIAL USE, WILL NOT 
*    VIOLATE ANY THIRD PARTY RIGHTS, WILL PROVIDE THE INTENDED OR DESIRED
*    RESULTS, OR OPERATE AS YOU INTENDED OR AS MAY BE INDICATED BY ROBOPLAN. 
*    YOU HEREBY WAIVE, AGREE NOT TO ASSERT AGAINST, AND RELEASE ROBOPLAN, 
*    ITS LICENSORS AND AFFILIATES FROM, ANY CLAIMS IN CONNECTION WITH ANY OF 
*    THE ABOVE. 
********************************************************/

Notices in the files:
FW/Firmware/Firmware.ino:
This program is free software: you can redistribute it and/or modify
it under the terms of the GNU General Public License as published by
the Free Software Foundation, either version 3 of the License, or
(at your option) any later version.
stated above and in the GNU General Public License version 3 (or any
